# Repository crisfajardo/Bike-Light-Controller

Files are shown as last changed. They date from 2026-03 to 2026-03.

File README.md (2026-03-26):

# 🚲 Bike-Light-Controller (Smart Cycling System)

This repository hosts a specialized embedded system designed for conventional bicycles, developed as a final project for my **Bachelor's Degree in Electronic and Telecommunications Engineering**.

The system transforms a standard bike into a "smart" vehicle by automating safety lighting through real-time sensor data fusion.

---

## 🚀 Overview
The **Bike-Light-Controller** manages visibility and signaling automatically. Using an **ESP32-S3** and the **Arduino IDE** framework, the system processes environmental light levels and motion dynamics to ensure rider safety.

### ✨ Key Features
* **Intelligent Brake Light:** Automatically triggers high-intensity rear LEDs when deceleration is detected via the **MPU6050**.
* **Adaptive Headlight:** Adjusts front lighting based on ambient lux levels measured by the **TEMT6000**.
* **Custom Hardware:** Professional PCB designed using **KiCad 9.0**, utilizing official **Espressif hardware libraries** for the ESP32-S3.
* **Real-time Processing:** Low-latency response to motion and lighting changes.

---

## 🛠️ Tech Stack

### Hardware Components
| Component | Function |
| :--- | :--- |
| **MCU** | **ESP32-S3** (Xtensa® 32-bit LX7 Dual-Core) |
| **IMU** | **MPU6050** (6-axis Accelerometer & Gyroscope) |
| **Light Sensor** | **TEMT6000** (High-precision ambient light sensor) |
| **PCB Design** | **KiCad 9.0** (Schematic & Layout) |

### Software & Firmware
* **Language:** C++ / Arduino Framework
* **IDE:** Arduino IDE 2.3.8
* **Communication:** I2C Protocol (Sensors) / MQTT (Optional for IoT telemetry)
* **Libraries:** `Adafruit_MPU6050`, `Adafruit_Sensor`, `Wire.h`

---

## 📂 Repository Structure

```text
├── Firmware/        # Source code (.ino) for the ESP32-S3
├── Hardware/        # KiCad 9.0 Project files (Schematics, PCB, Gerbers)
├── Docs/            # Datasheets, project report, and bibliography
└── Assets/          # Images, circuit diagrams, and 3D renders

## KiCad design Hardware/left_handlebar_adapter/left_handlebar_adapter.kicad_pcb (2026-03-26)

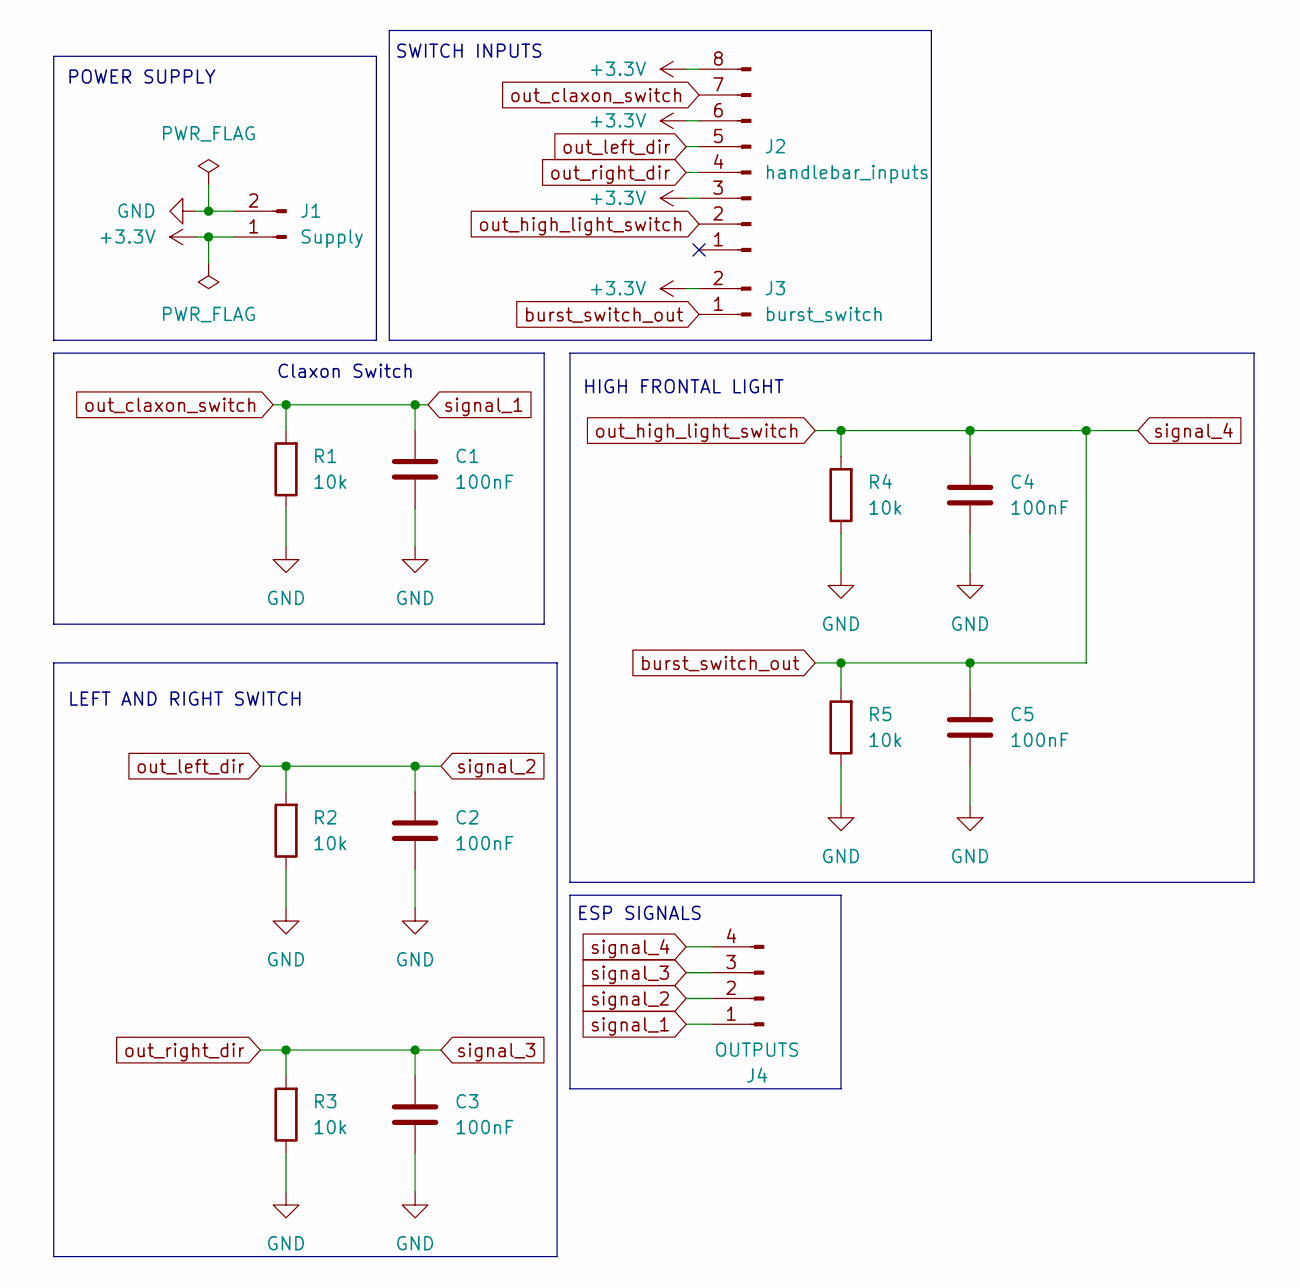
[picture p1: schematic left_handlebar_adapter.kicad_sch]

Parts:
C1, C2, C3, C4, C5: 100nF; C_Disc_D5.0mm_W2.5mm_P2.50mm
J1: Supply; PinHeader_1x02_P2.54mm_Vertical
J2: handlebar_inputs; PinHeader_1x08_P2.54mm_Vertical
J3: burst_switch; PinHeader_1x02_P2.54mm_Vertical
J4: OUTPUTS; PinHeader_1x04_P2.54mm_Vertical
R1, R2, R3, R4, R5: 10k; R_Axial_DIN0207_L6.3mm_D2.5mm_P7.62mm_Horizontal

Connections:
+3.3V: J1.1, J2.3, J2.6, J2.8, J3.2
GND: C1.2, C2.2, C3.2, C4.2, C5.2, J1.2, R1.1, R2.1, R3.1, R4.1, R5.1
burst_switch_out: C4.1, C5.1, J2.2, J3.1, J4.4, R4.2, R5.2
out_claxon_switch: C1.1, J2.7, J4.1, R1.2
out_left_dir: C2.1, J2.5, J4.2, R2.2
out_right_dir: C3.1, J2.4, J4.3, R3.2

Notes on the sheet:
POWER SUPPLY
ESP SIGNALS
SWITCH INPUTS
HIGH FRONTAL LIGHT
Claxon Switch
LEFT AND RIGHT SWITCH

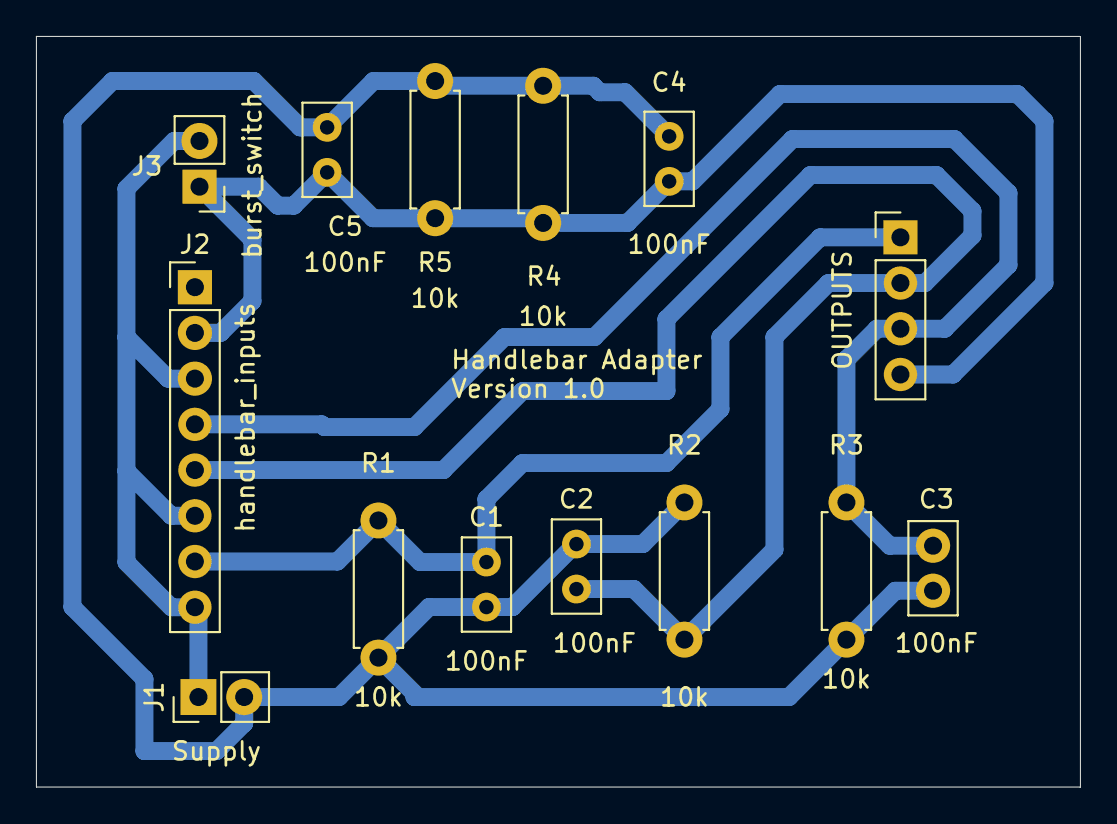
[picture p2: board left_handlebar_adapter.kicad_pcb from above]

Board: 2 copper layers, 58.0 x 41.7 mm, 14 parts (0 on the bottom side), 6 nets.

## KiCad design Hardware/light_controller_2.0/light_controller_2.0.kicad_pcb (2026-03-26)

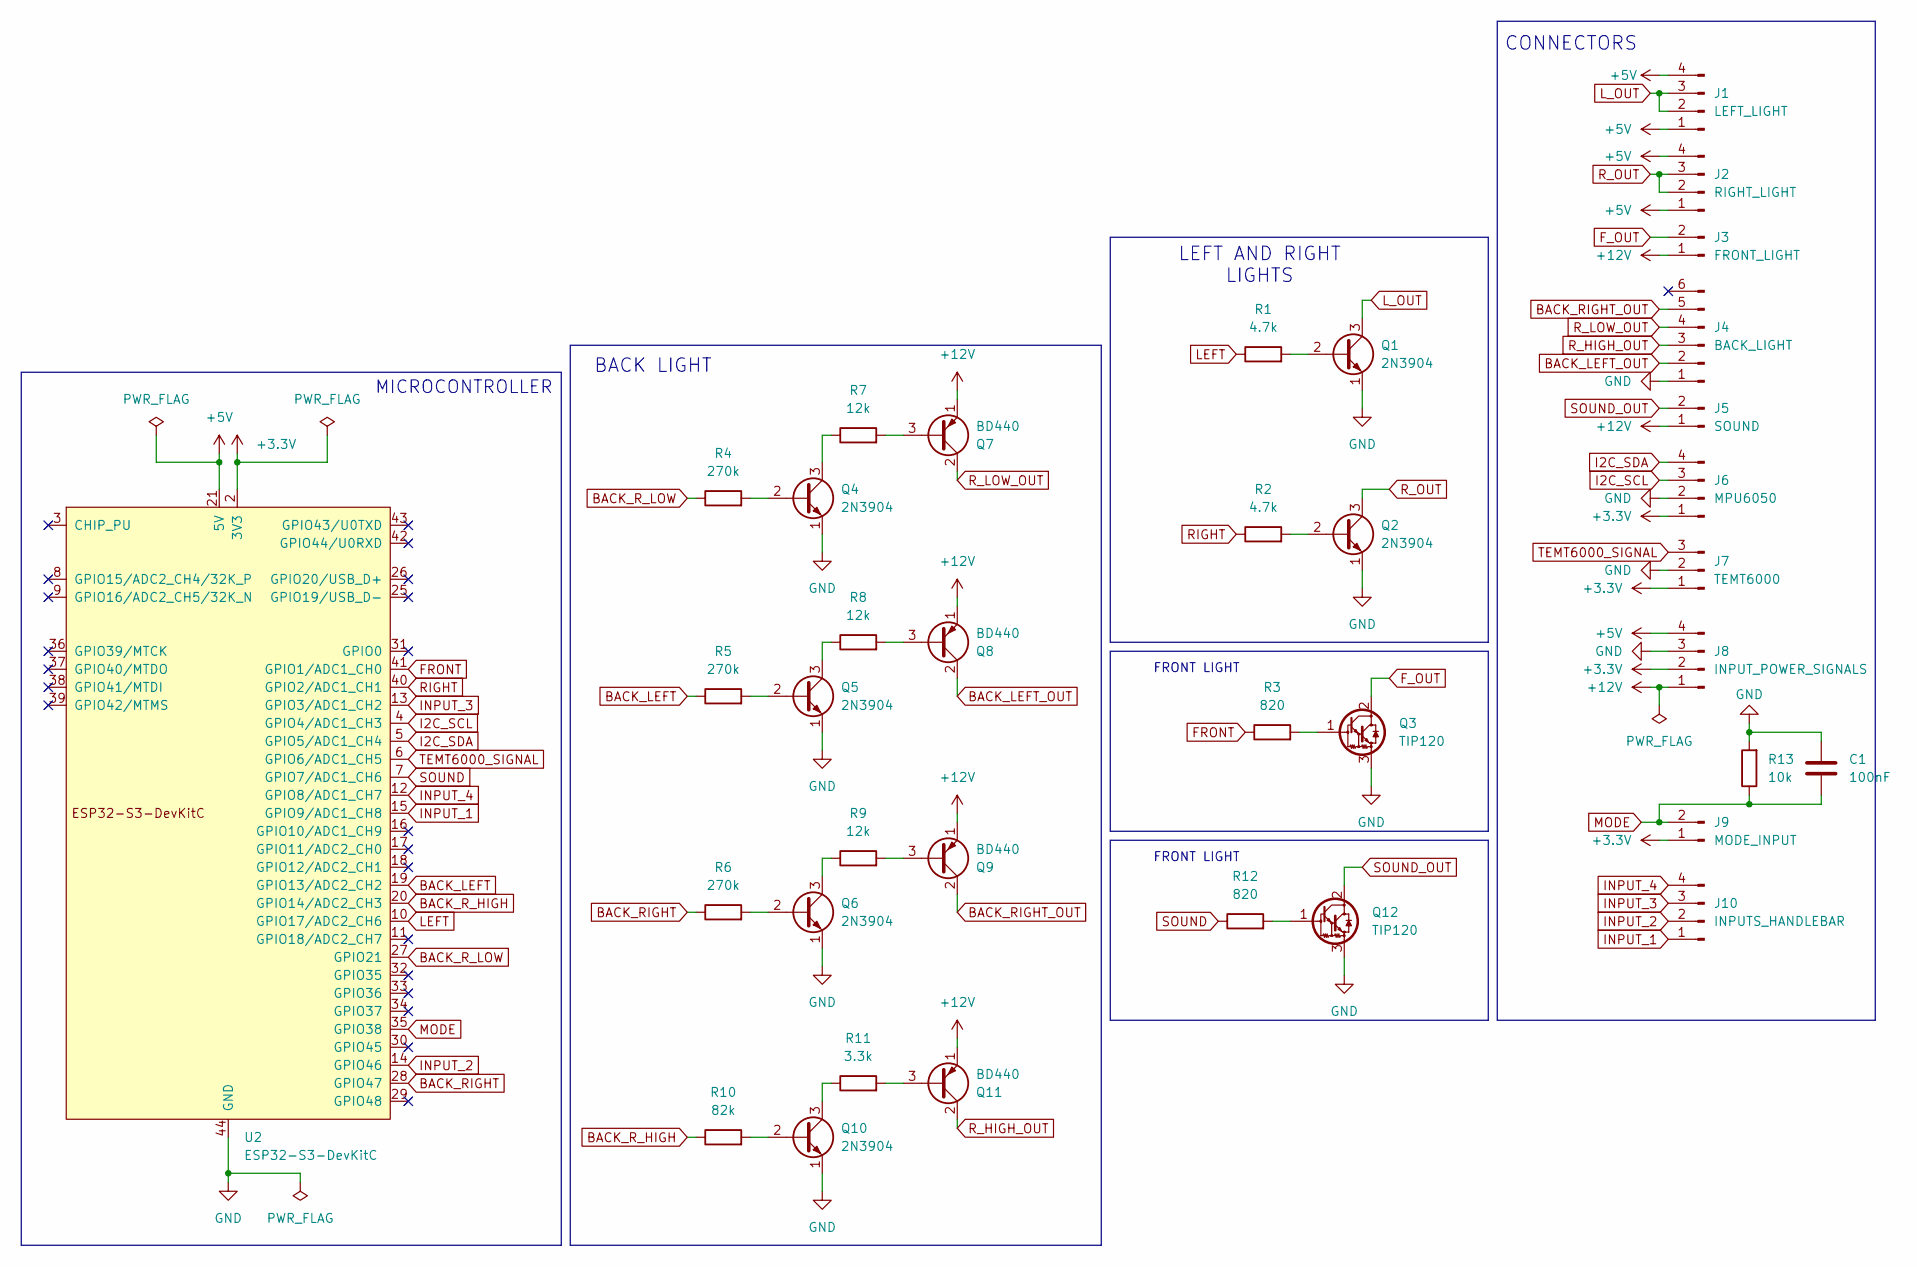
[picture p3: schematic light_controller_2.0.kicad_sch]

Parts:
C1: 100nF; C_Disc_D5.0mm_W2.5mm_P2.50mm
J1: LEFT_LIGHT; PinHeader_1x04_P2.54mm_Vertical
J2: RIGHT_LIGHT; PinHeader_1x04_P2.54mm_Vertical
J3: FRONT_LIGHT; PinHeader_1x02_P2.54mm_Vertical
J4: BACK_LIGHT; PinHeader_1x06_P2.54mm_Vertical
J5: SOUND; PinHeader_1x02_P2.54mm_Vertical
J6: MPU6050; PinHeader_1x04_P2.54mm_Vertical
J7: TEMT6000; PinHeader_1x03_P2.54mm_Vertical
J8: INPUT_POWER_SIGNALS; PinHeader_1x04_P2.54mm_Vertical
J9: MODE_INPUT; PinHeader_1x02_P2.54mm_Vertical
J10: INPUTS_HANDLEBAR; PinHeader_1x04_P2.54mm_Vertical
Q1, Q2, Q4, Q5, Q6, Q10: 2N3904; TO-92_Inline_Wide
Q3, Q12: TIP120; TO-220-3_Vertical
Q7, Q8, Q9, Q11: BD440; TO-126-3_Vertical
R1, R2: 4.7k; R_Axial_DIN0207_L6.3mm_D2.5mm_P7.62mm_Horizontal
R3, R12: 820; R_Axial_DIN0207_L6.3mm_D2.5mm_P7.62mm_Horizontal
R4, R5, R6: 270k; R_Axial_DIN0207_L6.3mm_D2.5mm_P7.62mm_Horizontal
R7, R8, R9: 12k; R_Axial_DIN0207_L6.3mm_D2.5mm_P7.62mm_Horizontal
R10: 82k; R_Axial_DIN0207_L6.3mm_D2.5mm_P7.62mm_Horizontal
R11: 3.3k; R_Axial_DIN0207_L6.3mm_D2.5mm_P7.62mm_Horizontal
R13: 10k; R_Axial_DIN0207_L6.3mm_D2.5mm_P7.62mm_Horizontal
U2: ESP32-S3-DevKitC

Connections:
+3.3V: J6.1, J7.1, J8.2, J9.1, U2.1 (3V3), U2.2 (3V3)
+5V: J1.1, J1.4, J2.1, J2.4, J8.4, U2.21 (5V)
+12V: J3.1, J5.1, J8.1, Q7.1 (E), Q8.1 (E), Q9.1 (E), Q11.1 (E)
BACK_LEFT: R5.1, U2.19 (GPIO13/ADC2_CH2)
BACK_LEFT_OUT: J4.2, Q8.2 (C)
BACK_RIGHT: R6.1, U2.28 (GPIO47)
BACK_RIGHT_OUT: J4.5, Q9.2 (C)
BACK_R_HIGH: R10.1, U2.20 (GPIO14/ADC2_CH3)
BACK_R_LOW: R4.1, U2.27 (GPIO21)
FRONT: R3.1, U2.41 (GPIO1/ADC1_CH0)
F_OUT: J3.2, Q3.2 (C)
GND: C1.1, J4.1, J6.2, J7.2, J8.3, Q1.1 (E), Q2.1 (E), Q3.3 (E), Q4.1 (E), Q5.1 (E), Q6.1 (E), Q10.1 (E), Q12.3 (E), R13.2, U2.22 (GND), U2.23 (GND), U2.24 (GND), U2.44 (GND)
I2C_SCL: J6.3, U2.4 (GPIO4/ADC1_CH3)
I2C_SDA: J6.4, U2.5 (GPIO5/ADC1_CH4)
INPUT_1: J10.1, U2.15 (GPIO9/ADC1_CH8)
INPUT_2: J10.2, U2.14 (GPIO46)
INPUT_3: J10.3, U2.13 (GPIO3/ADC1_CH2)
INPUT_4: J10.4, U2.12 (GPIO8/ADC1_CH7)
LEFT: R1.1, U2.10 (GPIO17/ADC2_CH6)
L_OUT: J1.2, J1.3, Q1.3 (C)
MODE: C1.2, J9.2, R13.1, U2.35 (GPIO38)
unnamed: Q1.2 (B), R1.2
unnamed: Q2.2 (B), R2.2
unnamed: Q3.1 (B), R3.2
unnamed: Q4.2 (B), R4.2
unnamed: Q4.3 (C), R7.1
unnamed: Q5.2 (B), R5.2
unnamed: Q5.3 (C), R8.1
unnamed: Q6.2 (B), R6.2
unnamed: Q6.3 (C), R9.1
unnamed: Q7.3 (B), R7.2
unnamed: Q8.3 (B), R8.2
unnamed: Q9.3 (B), R9.2
unnamed: Q10.2 (B), R10.2
unnamed: Q10.3 (C), R11.1
unnamed: Q11.3 (B), R11.2
unnamed: Q12.1 (B), R12.2
RIGHT: R2.1, U2.40 (GPIO2/ADC1_CH1)
R_HIGH_OUT: J4.3, Q11.2 (C)
R_LOW_OUT: J4.4, Q7.2 (C)
R_OUT: J2.2, J2.3, Q2.3 (C)
SOUND: R12.1, U2.7 (GPIO7/ADC1_CH6)
SOUND_OUT: J5.2, Q12.2 (C)
TEMT6000_SIGNAL: J7.3, U2.6 (GPIO6/ADC1_CH5)

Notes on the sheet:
CONNECTORS
LEFT AND RIGHT LIGHTS
MICROCONTROLLER
FRONT LIGHT
BACK LIGHT

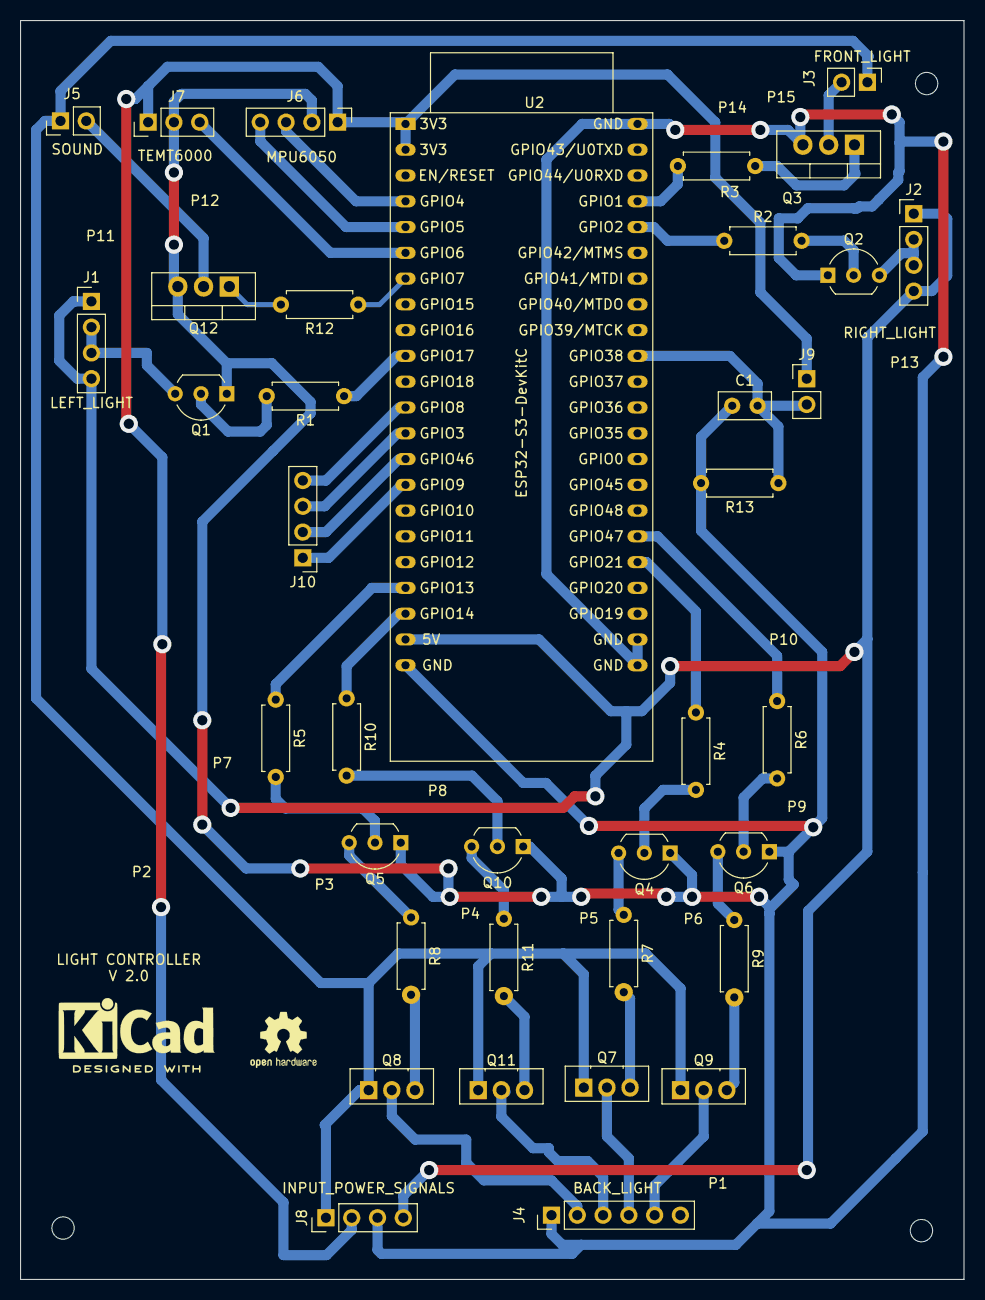
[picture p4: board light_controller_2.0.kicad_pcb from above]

Board: 2 copper layers, 93.0 x 124.0 mm, 37 parts (0 on the bottom side), 44 nets.

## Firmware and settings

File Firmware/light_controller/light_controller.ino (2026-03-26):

// ============================================================
//  Light Controller – ESP32-S3
//  Basado en diagrama de estados: s0, sM, sA, sDir, sF, sC, sS, sE
//  IDE: Arduino IDE  |  Board: ESP32-S3
// ============================================================

#include <Wire.h>
#include <Adafruit_MPU6050.h>   // Librería: Adafruit MPU6050 (Library Manager)
#include <Adafruit_Sensor.h>    // Dependencia de Adafruit Unified Sensor

// ─────────────────────────────────────────────
//  PINES
// ─────────────────────────────────────────────
#define PIN_LUZ_FRONTAL          1
#define PIN_LUZ_IZQ_FRONTAL     17
#define PIN_LUZ_DER_FRONTAL      2
#define PIN_LUZ_TRASERA_BAJA    21
#define PIN_LUZ_TRASERA_ALTA    14
#define PIN_LUZ_IZQ_TRASERA     13
#define PIN_LUZ_DER_TRASERA     47
#define PIN_I2C_SDA              5
#define PIN_I2C_SCL              4
#define PIN_TEMT6000             6   // Analógico
#define PIN_SWITCH_MODE         38
#define PIN_CLAXON_SWITCH        9
#define PIN_SWITCH_IZQ          46
#define PIN_SWITCH_DER           3
#define PIN_FRONT_LIGHT_SWITCH   8
#define PIN_CLAXON               7

// ─────────────────────────────────────────────
//  CANALES PWM (LEDC – ESP32)
// ─────────────────────────────────────────────
#define PWM_FREQ          1000   // Hz
#define PWM_RES              8   // bits → 0-255
// La nueva API ledcAttach() asigna el canal automáticamente por pin

// ─────────────────────────────────────────────
//  CONSTANTES DE COMPORTAMIENTO
// ─────────────────────────────────────────────
#define DELAY_LIGHTS        200   // ms – parpadeo direccionales

// Umbrales eje Y (m/s²) para modo automático
// Adafruit MPU6050 entrega aceleración en m/s² (±8g → ±78.4 m/s²)
#define UMBRAL_IZQ_Y      -3.0f   // girado a la izquierda si Y < este valor
#define UMBRAL_DER_Y       3.0f   // girado a la derecha  si Y > este valor

// Umbrales eje Z (m/s²) para detección de frenada
// Frenada: componente Z negativa al desacelerar
#define FRENO_LEVE       -2.0f   // frenada leve     → PWM 50%
#define FRENO_MODERADO   -5.0f   // frenada moderada → PWM 75%
// más negativo que FRENO_MODERADO → PWM 100%

// Intervalo de muestreo del MPU6050 (polling por millis)
#define MPU_SAMPLE_MS       20   // ms

// ─────────────────────────────────────────────
//  ESTADOS
// ─────────────────────────────────────────────
typedef enum {
  STATE_S0,    // Inicial / configuración
  STATE_SM,    // Manual
  STATE_SA,    // Automático
  STATE_SDIR,  // Control de direccionales
  STATE_SF,    // Control de luz frontal
  STATE_SC,    // Control de claxon
  STATE_SS,    // Control de stop
  STATE_SE     // Error
} State;

// ─────────────────────────────────────────────
//  VARIABLES GLOBALES
// ─────────────────────────────────────────────
volatile bool FLAG_SWITCH_MODE       = false;
volatile bool FLAG_CLAXON_SWITCH     = false;
volatile bool FLAG_SWITCH_IZQ        = false;
volatile bool FLAG_SWITCH_DER        = false;
volatile bool FLAG_FRONT_LIGHT_SWITCH= false;
volatile bool STOP_FLAG              = false;

// Adafruit MPU6050 entrega valores en m/s²  (accel) y rad/s (gyro)
float accelX = 0, accelY = 0, accelZ = 0;

uint8_t  front_pwm   = 128;   // 50% por defecto (0-255)
uint8_t  stop_pwm    = 0;

State    currentState = STATE_S0;
String   errorMsg     = "";

Adafruit_MPU6050 mpu;

// Temporización del muestreo del MPU6050 (polling con millis)
unsigned long lastMpuSample  = 0;

// Para parpadeo sin delay (sDir, sS)
unsigned long lastToggleDir  = 0;
unsigned long lastToggleSS   = 0;
bool          dirLightsOn    = false;
bool          ssLightsSwap   = false;

// ─────────────────────────────────────────────
//  ISR – Interrupciones de señales digitales
// ─────────────────────────────────────────────
void IRAM_ATTR isrSwitchMode()      { FLAG_SWITCH_MODE        = digitalRead(PIN_SWITCH_MODE); }
void IRAM_ATTR isrClaxon()          { FLAG_CLAXON_SWITCH      = digitalRead(PIN_CLAXON_SWITCH); }
void IRAM_ATTR isrSwitchIzq()       { FLAG_SWITCH_IZQ         = digitalRead(PIN_SWITCH_IZQ); }
void IRAM_ATTR isrSwitchDer()       { FLAG_SWITCH_DER         = digitalRead(PIN_SWITCH_DER); }
void IRAM_ATTR isrFrontLightSwitch(){ FLAG_FRONT_LIGHT_SWITCH = digitalRead(PIN_FRONT_LIGHT_SWITCH); }

// ─────────────────────────────────────────────
//  Función de muestreo del MPU6050 (polling)
//  Llamar desde el loop principal cada MPU_SAMPLE_MS
// ─────────────────────────────────────────────
void mpuSample() {
  sensors_event_t accel, gyro, temp;
  mpu.getEvent(&accel, &gyro, &temp);

  accelX = accel.acceleration.x;
  accelY = accel.acceleration.y;
  accelZ = accel.acceleration.z;

  // Detectar frenada: componente Z negativa (por debajo del umbral leve)
  // Umbrales en m/s²: FRENO_LEVE=-3, FRENO_MODERADO=-6
  if (accelZ < FRENO_LEVE) {
    STOP_FLAG = true;
    if      (accelZ > FRENO_LEVE)     stop_pwm = 128;   // leve     50%
    else if (accelZ > FRENO_MODERADO) stop_pwm = 191;   // moderada 75%
    else                               stop_pwm = 255;   // fuerte   100%
  } else {
    STOP_FLAG = false;
    stop_pwm  = 0;
  }
}

// ─────────────────────────────────────────────
//  HELPERS – PWM y GPIO
// ─────────────────────────────────────────────
void setFrontPWM(uint8_t duty) {
  ledcWrite(PIN_LUZ_FRONTAL, duty);
}

void setStopHighPWM(uint8_t duty) {
  ledcWrite(PIN_LUZ_TRASERA_ALTA, duty);
}

void apagaTodasLuces() {
  setFrontPWM(0);
  setStopHighPWM(0);
  digitalWrite(PIN_LUZ_IZQ_FRONTAL,  LOW);
  digitalWrite(PIN_LUZ_DER_FRONTAL,  LOW);
  digitalWrite(PIN_LUZ_TRASERA_BAJA, LOW);
  digitalWrite(PIN_LUZ_IZQ_TRASERA,  LOW);
  digitalWrite(PIN_LUZ_DER_TRASERA,  LOW);
  digitalWrite(PIN_CLAXON,           LOW);
}

// ─────────────────────────────────────────────
//  SETUP
// ─────────────────────────────────────────────
void setup() {
  Serial.begin(115200);
  currentState = STATE_S0;
}

// ─────────────────────────────────────────────
//  LOOP
// ─────────────────────────────────────────────
void loop() {
  // Muestreo periódico del MPU6050 (polling no bloqueante)
  unsigned long now = millis();
  if (now - lastMpuSample >= MPU_SAMPLE_MS) {
    lastMpuSample = now;
    mpuSample();
  }

  switch (currentState) {
    case STATE_S0:  state_s0();   break;
    case STATE_SM:  state_sM();   break;
    case STATE_SA:  state_sA();   break;
    case STATE_SDIR: state_sDir(); break;
    case STATE_SF:  state_sF();   break;
    case STATE_SC:  state_sC();   break;
    case STATE_SS:  state_sS();   break;
    case STATE_SE:  state_sE();   break;
  }
}

// ============================================================
//  IMPLEMENTACIÓN DE ESTADOS
// ============================================================

// ─────────────────────────────────────────────
//  s0 – Inicial y configuración
// ─────────────────────────────────────────────
void state_s0() {
  Serial.println("[s0] Iniciando sistema...");

  // 1. Configurar pines de salida
  pinMode(PIN_LUZ_FRONTAL,        OUTPUT);
  pinMode(PIN_LUZ_IZQ_FRONTAL,    OUTPUT);
  pinMode(PIN_LUZ_DER_FRONTAL,    OUTPUT);
  pinMode(PIN_LUZ_TRASERA_BAJA,   OUTPUT);
  pinMode(PIN_LUZ_TRASERA_ALTA,   OUTPUT);
  pinMode(PIN_LUZ_IZQ_TRASERA,    OUTPUT);
  pinMode(PIN_LUZ_DER_TRASERA,    OUTPUT);
  pinMode(PIN_CLAXON,             OUTPUT);

  // 2. Configurar pines de entrada
  pinMode(PIN_SWITCH_MODE,         INPUT);
  pinMode(PIN_CLAXON_SWITCH,       INPUT);
  pinMode(PIN_SWITCH_IZQ,          INPUT);
  pinMode(PIN_SWITCH_DER,          INPUT);
  pinMode(PIN_FRONT_LIGHT_SWITCH,  INPUT);

  // 3. Configurar canales PWM (nueva API LEDC: ledcAttach unifica setup y attach)
  if (!ledcAttach(PIN_LUZ_FRONTAL,      PWM_FREQ, PWM_RES)) {
    errorMsg = "LEDC: fallo al configurar luz frontal";
    currentState = STATE_SE;
    return;
  }
  if (!ledcAttach(PIN_LUZ_TRASERA_ALTA, PWM_FREQ, PWM_RES)) {
    errorMsg = "LEDC: fallo al configurar luz trasera alta";
    currentState = STATE_SE;
    return;
  }

  // 4. I2C y MPU6050 (Adafruit) – solo SDA/SCL, sin pin de interrupción
  Wire.begin(PIN_I2C_SDA, PIN_I2C_SCL);
  if (!mpu.begin()) {
    errorMsg = "MPU6050 no responde";
    currentState = STATE_SE;
    return;
  }
  // Rangos de trabajo: ±8g accel, 500°/s gyro
  mpu.setAccelerometerRange(MPU6050_RANGE_8_G);
  mpu.setGyroRange(MPU6050_RANGE_500_DEG);
  mpu.setFilterBandwidth(MPU6050_BAND_21_HZ);
  Serial.println("[s0] MPU6050 OK");

  // 5. Verificar TEMT6000 (lectura analógica básica)
  int temt = analogRead(PIN_TEMT6000);
  Serial.print("[s0] TEMT6000 lectura: ");
  Serial.println(temt);
  // analogRead siempre devuelve >= 0; se puede ampliar con umbral si es necesario

  // 6. Adjuntar interrupciones para señales digitales
  attachInterrupt(digitalPinToInterrupt(PIN_SWITCH_MODE),        isrSwitchMode,       CHANGE);
  attachInterrupt(digitalPinToInterrupt(PIN_CLAXON_SWITCH),      isrClaxon,           CHANGE);
  attachInterrupt(digitalPinToInterrupt(PIN_SWITCH_IZQ),         isrSwitchIzq,        CHANGE);
  attachInterrupt(digitalPinToInterrupt(PIN_SWITCH_DER),         isrSwitchDer,        CHANGE);
  attachInterrupt(digitalPinToInterrupt(PIN_FRONT_LIGHT_SWITCH), isrFrontLightSwitch, CHANGE);

  // 7. Inicializar temporizador de muestreo del MPU6050
  lastMpuSample = millis();

  Serial.println("[s0] Configuracion completada → sM");
  currentState = STATE_SM;
}

// ─────────────────────────────────────────────
//  sM – Estado Manual
// ─────────────────────────────────────────────
void state_sM() {
  // Luz frontal siempre al 50%
  front_pwm = 128;
  setFrontPWM(front_pwm);

  // Luz trasera baja siempre encendida
  digitalWrite(PIN_LUZ_TRASERA_BAJA, HIGH);

  // --- Evaluación de transiciones (prioridad descendente) ---

  // Modo automático
  if (FLAG_SWITCH_MODE) {
    apagaTodasLuces();
    currentState = STATE_SA;
    return;
  }

  // Frenada
  if (STOP_FLAG) {
    currentState = STATE_SS;
    return;
  }

  // Direccionales (no pueden estar las dos a la vez)
  if (FLAG_SWITCH_IZQ && FLAG_SWITCH_DER) {
    errorMsg = "sM: SWITCH_IZQ y SWITCH_DER activos simultaneamente";
    currentState = STATE_SE;
    return;
  }
  if (FLAG_SWITCH_IZQ || FLAG_SWITCH_DER) {
    lastToggleDir = millis();
    dirLightsOn   = false;
    currentState  = STATE_SDIR;
    return;
  }

  // Luz frontal al 100%
  if (FLAG_FRONT_LIGHT_SWITCH) {
    currentState = STATE_SF;
    return;
  }

  // Claxon
  if (FLAG_CLAXON_SWITCH) {
    currentState = STATE_SC;
    return;
  }

  // Sin cambios: permanecer en sM
}

// ─────────────────────────────────────────────
//  sA – Estado Automático
// ─────────────────────────────────────────────
void state_sA() {
  // Volver a Manual si se desactiva SWITCH_MODE
  if (!FLAG_SWITCH_MODE) {
    apagaTodasLuces();
    front_pwm = 128;
    setFrontPWM(front_pwm);
    digitalWrite(PIN_LUZ_TRASERA_BAJA, HIGH);
    currentState = STATE_SM;
    return;
  }

  // Detectar frenada (STOP_FLAG actualizado por polling en loop)
  if (STOP_FLAG) {
    currentState = STATE_SS;
    return;
  }

  // Control de direccionales por MPU6050 eje Y
  if (accelY < UMBRAL_IZQ_Y) {
    // Girado a la izquierda
    digitalWrite(PIN_LUZ_IZQ_FRONTAL, HIGH);
    digitalWrite(PIN_LUZ_IZQ_TRASERA, HIGH);
    digitalWrite(PIN_LUZ_DER_FRONTAL, LOW);
    digitalWrite(PIN_LUZ_DER_TRASERA, LOW);
  } else if (accelY > UMBRAL_DER_Y) {
    // Girado a la derecha
    digitalWrite(PIN_LUZ_DER_FRONTAL, HIGH);
    digitalWrite(PIN_LUZ_DER_TRASERA, HIGH);
    digitalWrite(PIN_LUZ_IZQ_FRONTAL, LOW);
    digitalWrite(PIN_LUZ_IZQ_TRASERA, LOW);
  } else {
    // Centrado
    digitalWrite(PIN_LUZ_IZQ_FRONTAL, LOW);
    digitalWrite(PIN_LUZ_IZQ_TRASERA, LOW);
    digitalWrite(PIN_LUZ_DER_FRONTAL, LOW);
    digitalWrite(PIN_LUZ_DER_TRASERA, LOW);
  }
}

// ─────────────────────────────────────────────
//  sDir – Control de Direccionales
// ─────────────────────────────────────────────
void state_sDir() {
  // Error: ambas activas
  if (FLAG_SWITCH_IZQ && FLAG_SWITCH_DER) {
    apagaTodasLuces();
    errorMsg = "sDir: Ambas direccionales activas";
    currentState = STATE_SE;
    return;
  }

  // Fin del estado: ninguna activa → volver a sM
  if (!FLAG_SWITCH_IZQ && !FLAG_SWITCH_DER) {
    digitalWrite(PIN_LUZ_IZQ_FRONTAL, LOW);
    digitalWrite(PIN_LUZ_IZQ_TRASERA, LOW);
    digitalWrite(PIN_LUZ_DER_FRONTAL, LOW);
    digitalWrite(PIN_LUZ_DER_TRASERA, LOW);
    currentState = STATE_SM;
    return;
  }

  // Parpadeo no bloqueante con millis()
  unsigned long now = millis();
  if (now - lastToggleDir >= DELAY_LIGHTS) {
    lastToggleDir = now;
    dirLightsOn   = !dirLightsOn;

    if (FLAG_SWITCH_IZQ) {
      digitalWrite(PIN_LUZ_IZQ_FRONTAL, dirLightsOn ? HIGH : LOW);
      digitalWrite(PIN_LUZ_IZQ_TRASERA, dirLightsOn ? HIGH : LOW);
      // Apagar lado contrario por seguridad
      digitalWrite(PIN_LUZ_DER_FRONTAL, LOW);
      digitalWrite(PIN_LUZ_DER_TRASERA, LOW);
    } else if (FLAG_SWITCH_DER) {
      digitalWrite(PIN_LUZ_DER_FRONTAL, dirLightsOn ? HIGH : LOW);
      digitalWrite(PIN_LUZ_DER_TRASERA, dirLightsOn ? HIGH : LOW);
      digitalWrite(PIN_LUZ_IZQ_FRONTAL, LOW);
      digitalWrite(PIN_LUZ_IZQ_TRASERA, LOW);
    }
  }

  // Seguir monitoreando frenada incluso en sDir
  if (STOP_FLAG) {
    // Salir temporalmente a sS; al volver se retomará sDir
    currentState = STATE_SS;
  }
}

// ─────────────────────────────────────────────
//  sF – Control de Luz Frontal (100%)
// ─────────────────────────────────────────────
void state_sF() {
  front_pwm = 255;   // 100% duty cycle
  setFrontPWM(front_pwm);

  // Permanecer hasta que se suelte el switch
  if (!FLAG_FRONT_LIGHT_SWITCH) {
    front_pwm = 128;
    setFrontPWM(front_pwm);
    currentState = STATE_SM;
  }
  // Si ocurre error, se puede agregar aquí lógica adicional
}

// ─────────────────────────────────────────────
//  sC – Control de Claxon
// ─────────────────────────────────────────────
void state_sC() {
  digitalWrite(PIN_CLAXON, HIGH);

  if (!FLAG_CLAXON_SWITCH) {
    digitalWrite(PIN_CLAXON, LOW);
    currentState = STATE_SM;
  }
}

// ─────────────────────────────────────────────
//  sS – Control de Stop
// ─────────────────────────────────────────────
void state_sS() {
  // Determinar nivel de frenada y duty cycle
  uint8_t duty;
  if      (accelZ > FRENO_LEVE)     duty = 128;   // leve     50%
  else if (accelZ > FRENO_MODERADO) duty = 191;   // moderada 75%
  else                               duty = 255;   // fuerte   100%

  // Parpadeo no bloqueante de la luz trasera alta
  unsigned long now = millis();
  if (now - lastToggleSS >= DELAY_LIGHTS) {
    lastToggleSS  = now;
    ssLightsSwap  = !ssLightsSwap;

    if (ssLightsSwap) {
      setStopHighPWM(duty);
      digitalWrite(PIN_LUZ_TRASERA_BAJA, LOW);
    } else {
      setStopHighPWM(0);
      digitalWrite(PIN_LUZ_TRASERA_BAJA, HIGH);
    }
  }

  // Fin de frenada → volver a sM
  if (!STOP_FLAG) {
    setStopHighPWM(0);
    digitalWrite(PIN_LUZ_TRASERA_BAJA, HIGH);
    currentState = STATE_SM;
  }
}

// ─────────────────────────────────────────────
//  sE – Estado de Error (loop infinito)
// ─────────────────────────────────────────────
void state_sE() {
  // Apagar todo por seguridad
  apagaTodasLuces();

  // Reportar error indefinidamente por serial
  while (true) {
    Serial.print("[ERROR] ");
    Serial.println(errorMsg);
    delay(1000);
  }
}
